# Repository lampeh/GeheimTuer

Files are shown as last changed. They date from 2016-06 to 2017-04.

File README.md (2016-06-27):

# GeheimTuer
Simple sliding door control at Attraktor Makerspace

User Interface:
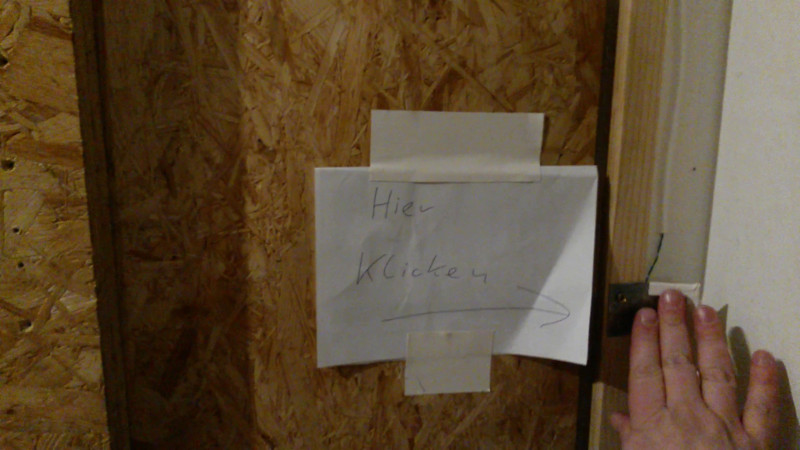
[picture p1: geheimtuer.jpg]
GeheimTuer (http://static.openchaos.org/attraktor/bastel/geheimtuer.mp4)


Prototype 1:
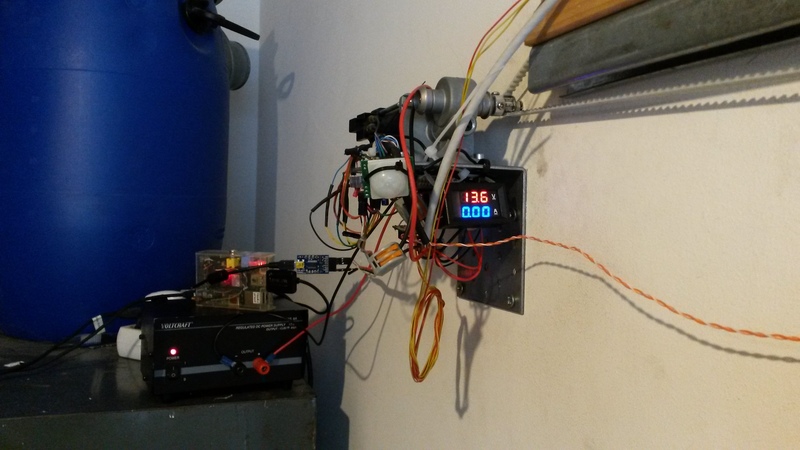
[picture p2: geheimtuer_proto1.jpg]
Prototype 1


Prototype 2:
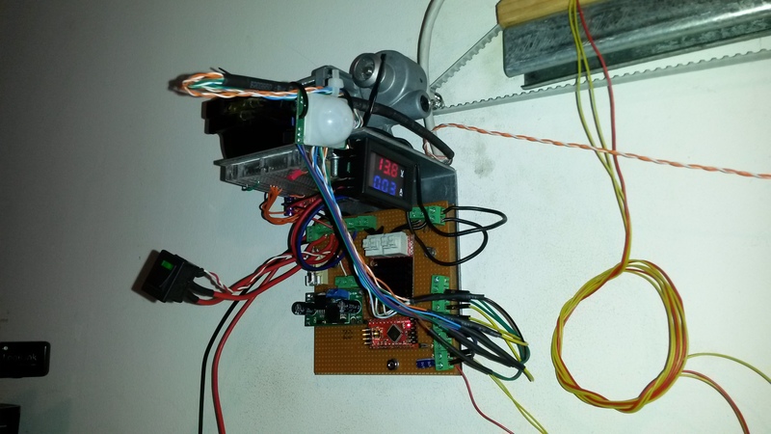
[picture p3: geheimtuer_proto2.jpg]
Prototype 2


Prototype 3, now with laser case and cooling fan:
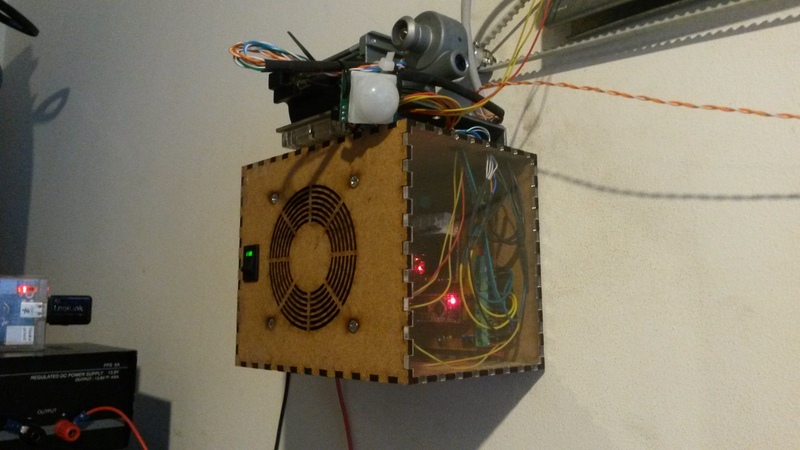
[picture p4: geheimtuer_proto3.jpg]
Prototype 3


Spaghetti Schematics. Just a reminder to myself:
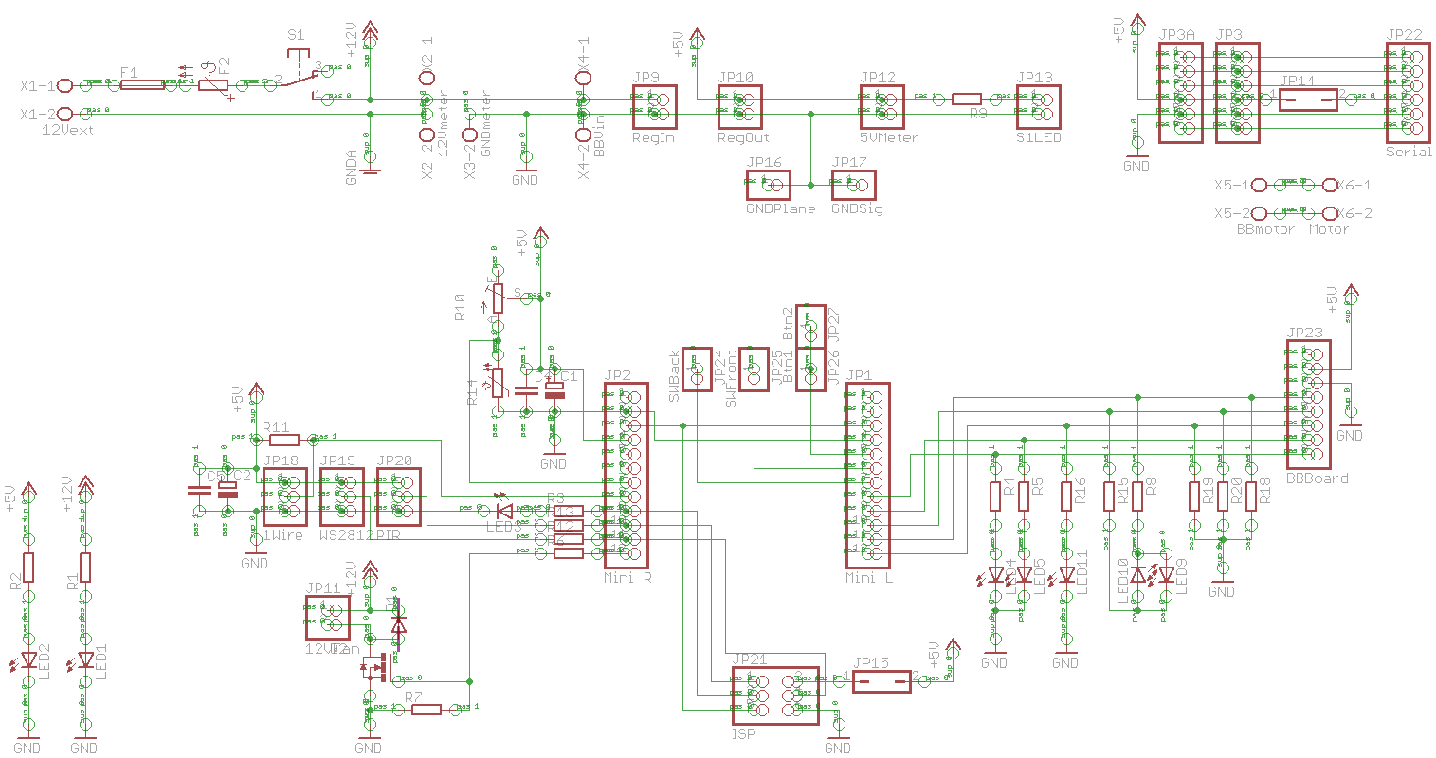
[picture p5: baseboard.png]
Baseboard


Case (created with [Tabbed Box Maker](https://github.com/paulh-rnd/TabbedBoxMaker)):
Case Cut

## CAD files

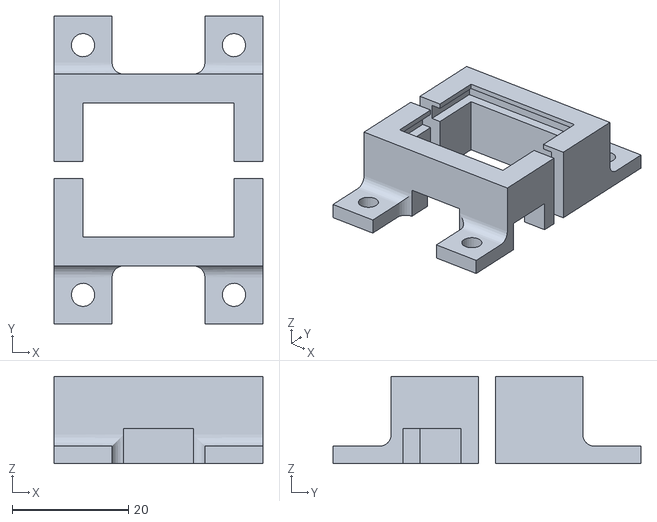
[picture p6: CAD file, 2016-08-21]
ledcover_bracket.stl
36.0 x 53.0 x 15.0

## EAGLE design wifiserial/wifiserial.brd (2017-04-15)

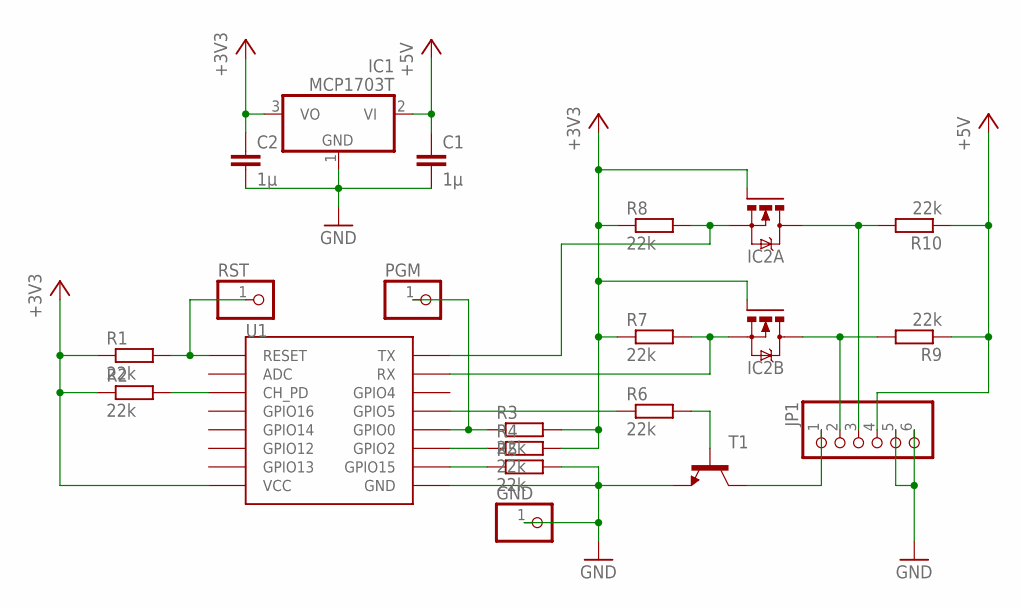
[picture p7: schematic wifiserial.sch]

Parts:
C1, C2: 1µ; C0805K
GND: PINHD-1X1; 1X01
IC1: MCP1703T; SOT-89
IC2: NFET2-SSOT6; SSOT-6
JP1: PINHD-1X6; 1X06
PGM: PINHD-1X1; 1X01
R1, R2, R3, R4, R5, R6, R7, R8, R9, R10: 22k; R0805
RST: PINHD-1X1; 1X01
T1: -NPN-SOT23-EBC; SOT23-EBC
U1: ESP12SMD; ESP12-SMD

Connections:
+3V3: C2.1, IC1.3 (VO), IC2.1 (G), IC2.3 (G), R1.1, R2.1, R3.2, R4.2, R7.1, R8.1, U1.VCC
+5V: C1.1, IC1.2 (VI), JP1.4, R9.1, R10.1
GND: C1.2, C2.2, GND.1, IC1.1 (GND), JP1.5, JP1.6, R5.2, T1.E, U1.GND
unnamed: PGM.1, R3.1, U1.GPIO0
unnamed: R4.1, U1.GPIO2
unnamed: R5.1, U1.GPIO15
unnamed: R2.2, U1.CH_PD
unnamed: R1.2, RST.1, U1.RESET
unnamed: R6.1, U1.GPIO5
unnamed: R6.2, T1.B
unnamed: IC2.4 (D), JP1.2, R9.2
unnamed: IC2.6 (D), JP1.3, R10.2
unnamed: JP1.1, T1.C
unnamed: IC2.5 (S), R8.2, U1.TXD0 (TX)
unnamed: IC2.2 (S), R7.2, U1.RXD0 (RX)

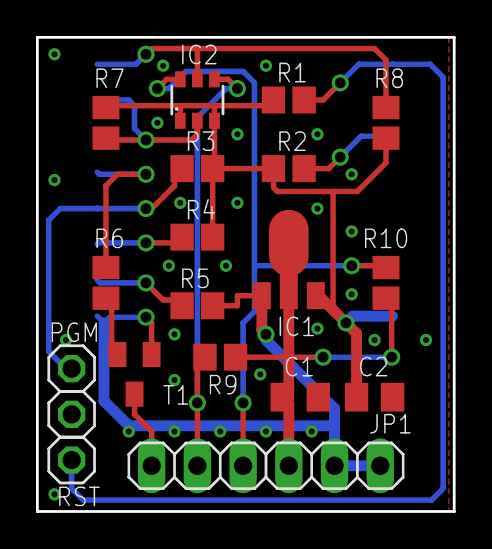
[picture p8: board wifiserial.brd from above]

Board: 2 copper layers, 23.2 x 26.3 mm, 20 parts (1 on the bottom side), 15 nets.

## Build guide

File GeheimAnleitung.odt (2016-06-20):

### Bedienungsanleitung:

1. Knopf drücken. Tür öffnet.
2. Türschwelle überschreiten. Wohlfühlen.
3. Tür schließt automatisch.

### Tür offenhalten:

1. Knopf drücken. Tür öffnet.
2. Bei offener Tür Knopf erneut drücken. Tür bleibt offen.
3. Zum Schließen der Tür Knopf ein weiteres Mal drücken.

### Bei Problemen während der Fahrt:

1. Knopf drücken. Tür stoppt.
2. Nach dem Problem Knopf erneut drücken. Tür öffnet.
3. Tür schließt automatisch.

Grün | Blinkt | Vorsicht! Tür schliesst gleich.
Grün | Faded | Tür zu. Alles gut.
Gelb | Blinkt | Bewegungsmelder meldet Bewegung. Tür bleibt solange offen.
Rot | Leuchtet | Tür blockiert durch Knopfdruck. Knopf erneut drücken.
Rot | Blinkt | Endschalter nicht erreicht. Knopf drücken zum Öffnen.
Rot | Faded | Nicht gut. Motortreiberstörung. Tür funktioniert nicht.
Blau | Leuchtet | Komisch. Techniker informieren. Tür funktioniert nicht.

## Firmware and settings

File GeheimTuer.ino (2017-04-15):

#include <avr/pgmspace.h>
#include <WS2812.h>
#include <OneWire.h>
#include "Debounce.h"
#include "Motor.h"


/* config */

#define VERSION "v1.1 " __TIMESTAMP__
#define MAXPIX 20  // LED stripe length
#define EXTRAPIX 4 // animation buffer, read window moves back and forth EXTRAPIX pixels

#if ((EXTRAPIX) > 255)
#error EXTRAPIX must fit uint8_t ledidx variable
#endif

// WS2812 data
const int ledPin = 11;

// I/O connections to bridge driver module
// https://www.olimex.com/Products/RobotParts/MotorDrivers/BB-VNH3SP30/
// https://www.olimex.com/Products/RobotParts/MotorDrivers/BB-VNH3SP30/resources/BB-VNH3SP30_schematic.pdf
const int motorDiagAPin = 5;
const int motorDiagBPin = 6;
const int motorInAPin = 7;
const int motorInBPin = 8;
const int motorPWMPin = 9;

Motor motor(motorDiagAPin, motorDiagBPin, motorInAPin, motorInBPin, motorPWMPin);

// end-stop switches, active-low
// Panasonic AZ7121
const int switchFront = 3; // front is at the closed position
const int switchBack = 4;

// wire-ORed buttons, active-low
const int switchTrigger = 2;

// PIR sensor, active-high
// based on BIS0001, e.g.: https://learn.adafruit.com/pir-passive-infrared-proximity-motion-sensor/
const int pirPin = 12;

// on-board status LED
const int statusLED = 13;

// on-board 1-wire sensors
OneWire ds(A0);

// external 1-wire bus
OneWire iButton(A1);

// PWM fan control
const int fanPWMPin = 10;


/* motor driver */

// slow seek to end-stop, used if door is in unknown position
const struct Motor::accelProfile accelProfileLow[] PROGMEM = {
  {
    maxMillis: 13000,
    stepMillis: 5,
    add: 1,
    factor: 1,
    minPWM: 0,
    maxPWM: 64,
  },
  {
    maxMillis: 0
  }
};

// normal operation
// try accelerating as fast as possible without skipping belt teeth
// belt tension limits torque. important safety feature
// TODO: install less stiff spring between belt and door to dampen the initial pull
const struct Motor::accelProfile accelProfileHigh[] PROGMEM = {
  { // accelerate and keep running
    maxMillis: 2500,
    stepMillis: 4,
    add: 1,
    factor: 1,
    minPWM: 0,
    maxPWM: 255,
  },
  { // slow down before end-stop
    maxMillis: 1500,
    stepMillis: 75,
    add: 0,
    factor: 0.9,
    minPWM: 50,
    maxPWM: 255,
  },
  { // seek end-stop
    maxMillis: 2500,
    stepMillis: 100,
    add: -1,
    factor: 1,
    minPWM: 50,
    maxPWM: 64,
  },
  {
    maxMillis: 0
  }
};

struct Motor::accelProfile currentProfile; // RAM-cached profile block
const struct Motor::accelProfile *accelProfile; // pointer to current profile block in progmem


/* WS2812 LEDs */

cRGB leds[MAXPIX + EXTRAPIX];
cRGB tmp_leds[MAXPIX]; // temp array for fading and blinking
cRGB *ledptr; // read pointer for WS2812 library, points to start of window

// requires custom changes to accept uint8_t** argument
WS2812 LED(MAXPIX, &ledptr);

enum ledMode { ledSolid, ledFade, ledBlink, ledForward, ledBackward } ledMode;

// mode-dependent state
union ledState {
  uint8_t ledidx;
  signed int fader;
  bool blink_off;
} ledState;

// pre-defined colors. GRB order, g++ doesn't implement out-of-order initializers
const cRGB traktor = {g: 0xB8 / 7, r: 0x67 / 7, b: 0xDC / 7}; // https://wiki.attraktor.org/Corporate_Identity
const cRGB black = {g: 0x00, r: 0x00, b: 0x00};
const cRGB white = {g: 0x1F, r: 0x1F, b: 0x1F};
const cRGB red = {g: 0x00, r: 0x1F, b: 0x00};
const cRGB yellow = {g: 0x1F, r: 0x1F, b: 0x00};
const cRGB green = {g: 0x1F, r: 0x00, b: 0x00};
const cRGB blue = {g: 0x00, r: 0x00, b: 0x1F};


/* unsorted variables below. TODO: refactor & cleanup */

// buttons & switches do different things in different states
enum doorStates { doorClosed, doorOpening, doorOpen, doorClosing, doorBlocked, doorBlockedPir, doorError } doorState;

double drivePWM;

// TODO: the timing system has some quirks. think again or document

unsigned long lastMillis = 0; // last loop's millis() result

unsigned long driveMillis;
unsigned long driveProfileMillis;
unsigned long driveTotalMillis;

const unsigned long openInterval = 3000; // ms before the door closes again, unless blocked by button
unsigned long openMillis = 0;

const unsigned long debounceInterval = 2; // shift inputs into debounce register every debounceInterval ms
unsigned long debounceMillis = 0;

const unsigned int debounceIgnoreInterval = 150; // ignore buttons for debounceIgnoreInterval*debounceInterval ms
unsigned int debounceIgnore = 0;

// TODO: use structured profiles
unsigned long ledMillis = 0;
const unsigned long ledSolidInterval = 500; // constantly update LED stripe in solid mode
const unsigned long ledFadeInterval = 40;
const unsigned long ledBlinkInterval = 500;
unsigned long ledMoveInterval; // shift LED window every X ms - varied by drivePWM

const unsigned long ledMoveMin = 45; // minimum move interval if drivePWM == 255
const unsigned long ledMoveMax = 300; // maximum move interval if drivePWM == 0

const unsigned int dsMax = 3; // register at most dsMax DS18B20 sensors
byte dsAddrs[dsMax][8]; // 1-wire addresses
byte dsCount; // registered sensors
signed int dsResults[dsMax];

unsigned long dsMillis = 0;
const unsigned long dsInterval = 1000; // sensor read interval
const signed int tempMax = 38 / 0.0625; // run fan at full speed above tempMax
const signed int tempMin = 30 / 0.0625; // run fan at minimum speed at tempMin
const signed int tempHyst = 2 / 0.0625; // shut off fan at tempMin-tempHyst

union sensorData {
  uint8_t scratchpad[9];
  struct {
    int16_t temperature;
    union {
      uint16_t userdata;
      struct {
        int8_t th;
        int8_t tl;
      };
    };
    union {
      uint8_t config;
      struct {
        uint8_t : 5;
        uint8_t resolution : 2;
        uint8_t : 1;
      };
    };
    uint8_t reserved0, reserved1, reserved2;
    uint8_t crc;
  };
};

byte fanPWM;
const byte fanMin = 170; // minimum PWM limit
const byte fanMax = 255; // maximum PWM limit
bool fanOverride = false; // temperature control disabled if true

PinDebounce motorDiagA(motorDiagAPin);
PinDebounce motorDiagB(motorDiagBPin);

PinDebounce swFront(switchFront);
PinDebounce swBack(switchBack);
PinDebounce swTrigger(switchTrigger);
PinDebounce pirTrigger(pirPin);

unsigned long iButtonMillis = 0;
const unsigned long iButtonInterval = 40; // ms between scans for iButton devices on external 1-wire bus
Debounce iButtonTrigger(4); // 4bit debounce -> 3 successive iButton reads to trigger


void debug(const __FlashStringHelper *const string) {
  Serial.print(lastMillis);
  Serial.write(' ');
  Serial.print(string);
}


__attribute__((always_inline))
void setup() {
  Serial.begin(115200);
  debug(F("\r\nGeheimTuer " VERSION "\r\nDoor control init\r\n"));

  // disable driver bridges until setup complete
  motor.disable();

  pinMode(statusLED, OUTPUT);
  digitalWrite(statusLED, HIGH);

  // start fan on full speed
  pinMode(fanPWMPin, OUTPUT);
  digitalWrite(fanPWMPin, HIGH);
  fanPWM = 255;

  // initialize WS2812 LEDs
  setLeds1(traktor, ledSolid);
  ledptr = &leds[0];
  LED.setOutput(ledPin);
  LED.sync();

  // TODO: check driver power dissipation
  // base PWM frequency is ~31kHz. any divisor other than 1 makes the motor whine
  // VNH3SP30 datasheet limits the input PWM frequency to 10kHz. MOSFETs in thermal danger?
  setPwmFrequency(motorPWMPin, 1); // also affects fan PWM output

  digitalWrite(motorPWMPin, LOW);
  pinMode(motorPWMPin, OUTPUT);

  digitalWrite(motorInAPin, LOW);
  pinMode(motorInAPin, OUTPUT);

  digitalWrite(motorInBPin, LOW);
  pinMode(motorInBPin, OUTPUT);

  pinMode(switchFront, INPUT_PULLUP);
  pinMode(switchBack, INPUT_PULLUP);

  pinMode(switchTrigger, INPUT_PULLUP);

  pinMode(pirPin, INPUT);

  // register sensors
  dsCount = scan1Wire(dsAddrs, dsMax);

  // initialize debounce registers, assume steady state
  swFront.init();
  swBack.init();
  swTrigger.init();
  pirTrigger.init();

  iButtonTrigger.init(searchButton());

  debug(F("Door status: "));

  if (swTrigger() == LOW || iButtonTrigger() == HIGH || (swFront() == LOW && swBack() == LOW)) {
    doorState = doorError;
    setLeds1(blue, ledSolid);
    Serial.print(F("ERROR\r\n"));
  } else if (swFront() == LOW) {
    doorState = doorClosed;
    setLeds1(green, ledFade);
    Serial.print(F("closed\r\n"));
  } else {
    doorState = doorBlocked;
    setLeds1(red, ledSolid);
    Serial.print(F("blocked\r\n"));
  }

  if (doorState != doorError) {
    if (doorState != doorBlocked) {
      motor.brake();
    } else {
      motor.free();
    }

    // enable driver
    motor.enable();

    // diag pull-ups should have brought the lines up by now
    motorDiagA.init();
    motorDiagB.init();
  }

  digitalWrite(statusLED, LOW);
}


__attribute__((always_inline))
void loop() {
  unsigned long elapsedMillis;
  unsigned long currentMillis;

  currentMillis = millis();


  // fast debounce driver error signals to filter short glitches
  motorDiagA.update();
  motorDiagB.update();

  // The WAM is overheating!
  if ((motorDiagA() == LOW || motorDiagB() == LOW) && doorState != doorError) {
    motor.free();
    debug(F("Motor driver error condition - door disabled\r\n"));
    setLeds1(red, ledFade);
    doorState = doorError;
  }


  if (currentMillis == lastMillis) {
    // everything below runs on a ms scale
    return;
  }

  // let the processor handle the overflow
  elapsedMillis = currentMillis - lastMillis;
  lastMillis = currentMillis;
  // assume that none of the following intervals overflow


  debounceMillis += elapsedMillis;
  if (debounceMillis >= debounceInterval) {
    debounceMillis = 0;

    if (!debounceIgnore) {
      swTrigger.update();
    } else {
      debounceIgnore--;
    }

    pirTrigger.update();
    swFront.update();
    swBack.update();
  }


  iButtonMillis += elapsedMillis;
  if (iButtonMillis >= iButtonInterval) {
    iButtonMillis = 0;

    iButtonTrigger.update(searchButton());

    if (iButtonTrigger() == HIGH) {
      swTrigger(LOW);
      iButtonTrigger(LOW);
    }
  }


/*
  // remote debugging aid
  // TODO: formalize the commands
  if (Serial.available()) {
    switch (Serial.read()) {
      case 'x':
        swTrigger(LOW); break;
      case 'X':
        swTrigger(HIGH); break;
      case 'b':
        swBack(LOW); break;
      case 'B':
        swBack(HIGH); break;
      case 'f':
        swFront(LOW); break;
      case 'F':
        swFront(HIGH); break;
      case 'i':
        pirTrigger(HIGH); break;
      case 'I':
        pirTrigger(LOW); break;
      case 'm':
        debug(F("Door status: "));
        Serial.println(doorState);
        break;
      case 'h':
        motor.disable();
        setLeds1(red, ledFade);
        doorState = doorError;
        break;
      case 'r':
        motor.enable();
        setLeds1(red, ledSolid);
        doorState = doorBlocked;
        break;
      case 'k': {
          const cRGB white255 = {g: 0xFF, r: 0xFF, b: 0xFF};
          setLeds1(white255, ledSolid);
          break;
        }
      case 'K':
        setLeds1(black, ledSolid);
        break;
      case '1':
        dsCount = scan1Wire(dsAddrs, dsMax);
        break;
      case 'l':
        debug(F("Fan full\r\n"));
        digitalWrite(fanPWMPin, HIGH);
        fanOverride = true;
        fanPWM = 255;
        break;
      case 'L':
        fanOverride = false;
        break;
    }
  }
*/


  // add up dsMillis early, so the door driver can reset it
  dsMillis += elapsedMillis;


  switch (doorState) {
    case doorClosed:
      // wait until a button is pressed or the front switch opens
      if (swTrigger() == LOW || swFront() == HIGH) {
        if (swTrigger() == LOW) {
          swTrigger(HIGH); // re-arm swTrigger
          debounceIgnore = debounceIgnoreInterval;
          debug(F("Button switch triggered - opening door\r\n"));
          initDrive(Motor::motorBackward, accelProfileHigh);
        } else {
          // maybe someone tried to pull the door open
          // TODO: or the door slams too fast into the end-stop and rebounds. align profile & inertial reality
          debug(F("Front switch triggered - opening door\r\n"));
          initDrive(Motor::motorBackward, accelProfileLow);
        }
        setLeds2(white, black, EXTRAPIX, ledBackward);
        doorState = doorOpening;
      }
      break;

    case doorOpen:
      // hold the door open if button pressed during openInterval
      if (swTrigger() == LOW) {
        motor.free();
        debug(F("Button switch triggered - door blocked\r\n"));
        swTrigger(HIGH);
        setLeds1(red, ledSolid);
        doorState = doorBlocked;
        break;
      }

      // reset timeout while sensor input is HIGH
      if (pirTrigger() == HIGH) {
        debug(F("Motion sensor triggered - door blocked by PIR\r\n"));
        setLeds1(yellow, ledBlink);
        doorState = doorBlockedPir;
        break;
      }

      openMillis += elapsedMillis;
      if (openMillis >= openInterval || swBack() == HIGH) {
        if (swBack() == HIGH) {
          // maybe someone tried to pull the door closed
          // TODO: or the door slams too fast into the end-stop and rebounds. align profile & inertial reality
          debug(F("Back switch triggered - closing door\r\n"));
          initDrive(Motor::motorForward, accelProfileLow);
        } else {
          debug(F("openInterval timeout - closing door\r\n"));
          initDrive(Motor::motorForward, accelProfileHigh);
        }
        setLeds2(white, black, EXTRAPIX, ledForward);
        doorState = doorClosing;
      }
      break;

    case doorOpening:
      // are we there yet?
      if (swBack() == LOW) {
        motor.brake();
        debug(F("Back switch triggered - door open\r\n"));
        debug(F("Total ms: "));
        Serial.println(driveTotalMillis);
        openMillis = 0;
        setLeds1(green, ledBlink);
        doorState = doorOpen;
        break;
      }

    // fall-through to doorClosing

    case doorClosing:
      if (doorState == doorClosing && swFront() == LOW) {
        motor.brake();
        debug(F("Front switch triggered - door closed\r\n"));
        debug(F("Total ms: "));
        Serial.println(driveTotalMillis);
        setLeds1(green, ledFade);
        doorState = doorClosed;
        break;
      }

      // stop if button pressed while in motion
      if (swTrigger() == LOW) {
        motor.free(); // TODO: motor.brake() might be better for an emergency stop. doesn't make much different in our case, the belt skips and the door stops in both cases
        debug(F("Button switch triggered - door blocked\r\n"));
        swTrigger(HIGH);
        setLeds1(red, ledSolid);
        doorState = doorBlocked;
        break;
      }

      // keep fan on full while driving
      digitalWrite(fanPWMPin, HIGH);
      fanPWM = 255;

      // don't poll 1-wire temperature sensors while driving
      dsMillis = 0;

      driveTotalMillis += elapsedMillis;
      driveMillis += elapsedMillis;

      if (driveMillis >= currentProfile.stepMillis) {
        driveProfileMillis += driveMillis;
        driveMillis = 0;

        // switch to next profile step
        if (driveProfileMillis >= currentProfile.maxMillis) {
          driveProfileMillis = 0;

          // load profile block from progmem
          _memcpy_P(&currentProfile, ++accelProfile, sizeof(currentProfile));

          // end-stop not reached at end of profile, someone might be in the way
          if (currentProfile.maxMillis == 0) {
            motor.free();
            debug(F("End of profile - door blocked\r\n"));
            debug(F("Total ms: "));
            Serial.println(driveTotalMillis);
            setLeds1(red, ledBlink);
            doorState = doorBlocked;
            break;
          }

          debug(F("Next profile\r\n"));
        }

        // update PWM value
        double newDrivePWM = (drivePWM + currentProfile.add) * currentProfile.factor;

        if (newDrivePWM < currentProfile.minPWM) {
          newDrivePWM = currentProfile.minPWM;
        } else if (newDrivePWM > currentProfile.maxPWM) {
          newDrivePWM = currentProfile.maxPWM;
        }

        drivePWM = newDrivePWM;
        analogWrite(motorPWMPin, round(newDrivePWM));

        // update LED animation speed
        ledMoveInterval = ledMoveMin + (unsigned long)((255 - newDrivePWM) * ((double)(ledMoveMax - ledMoveMin) / 255));

        debug(F("Drive PWM: "));
        Serial.print(newDrivePWM);
        Serial.print(F(", ledMoveInterval: "));
        Serial.println(ledMoveInterval);
      }
      break;

    case doorBlockedPir:
      // motion stopped, return to work
      if (pirTrigger() == LOW) {
        if (swBack() == LOW) {
          debug(F("Motion sensor released - door open\r\n"));
          openMillis = 0;
          setLeds1(green, ledBlink);
          doorState = doorOpen;
        } else {
          debug(F("Motion sensor released - door blocked\r\n"));
          setLeds1(red, ledSolid);
          doorState = doorBlocked;
        }
      }

      // hold the door open if button pressed
      if (swTrigger() == LOW) {
        motor.free();
        debug(F("Button switch triggered - door blocked\r\n"));
        swTrigger(HIGH);
        setLeds1(red, ledSolid);
        doorState = doorBlocked;
      }
      break;

    case doorBlocked:
      // wait until a button is pressed
      if (swTrigger() == LOW) {
        swTrigger(HIGH);

        // close door only if end-stop is active
        if (swBack() == LOW) {
          debug(F("Button switch triggered - closing door\r\n"));
          ledMode = ledForward;
          doorState = doorClosing;
          initDrive(Motor::motorForward, accelProfileHigh);
        } else {
          debug(F("Button switch triggered - opening door\r\n"));
          ledMode = ledBackward;
          doorState = doorOpening;
          initDrive(Motor::motorBackward, accelProfileLow);
        }

        setLeds2(white, black, EXTRAPIX, ledMode);
      }
      break;

    case doorError:
      // wait until driver cools down
      if (motorDiagA() == HIGH && motorDiagB() == HIGH) {
        debug(F("Motor driver recovered - door blocked\r\n"));
        fanOverride = false;
        setLeds1(red, ledSolid);
        doorState = doorBlocked;
        //        digitalWrite(statusLED, LOW);
      } else {
        fanPWM = 255;
        fanOverride = true;
        digitalWrite(fanPWMPin, HIGH);
        digitalWrite(statusLED, HIGH);
      }
      break;

    default:
      motor.free();
      motor.disable();
      debug(F("BUG: invalid doorState value: "));
      Serial.print(doorState);
      Serial.print(F(" - door disabled\r\n"));
      setLeds1(blue, ledSolid);
      doorState = doorError;
      digitalWrite(statusLED, HIGH);
      break;
  }


  ledMillis += elapsedMillis;
  switch (ledMode) {
    case ledSolid:
      if (ledMillis >= ledSolidInterval) {
        ledMillis = 0;
        ledptr = &leds[0];
        LED.sync();
      }
      break;

    case ledFade: {
        if (ledMillis >= ledFadeInterval) {
          ledMillis = 0;

          // TODO: really scale the values. this is too cheap
          for (size_t i = 0; i < MAXPIX; i++) {
            tmp_leds[i].r = max(0, (int)leds[i].r - abs(ledState.fader));
            tmp_leds[i].g = max(0, (int)leds[i].g - abs(ledState.fader));
            tmp_leds[i].b = max(0, (int)leds[i].b - abs(ledState.fader));
          }

          if (ledState.fader++ >= 255) {
            ledState.fader = -254;
          }

          ledptr = &tmp_leds[0];

          // quick hack: blink outer LEDs if someone approaches the door
          // TODO: fix double period at fader counter limits
          if (pirTrigger() == HIGH) {
            if ((ledState.fader >> 4) % 2) {
              tmp_leds[0] = {g: 0xFF, r: 0xFF, b: 0x00};
              tmp_leds[MAXPIX - 1] = {g: 0xFF, r: 0xFF, b: 0x00};
            } else {
              tmp_leds[1] = {g: 0xFF, r: 0xFF, b: 0x00};
              tmp_leds[MAXPIX - 2] = {g: 0xFF, r: 0xFF, b: 0x00};
            }
          }

          LED.sync();
        }
        break;
      }

    case ledBlink:
      if (ledMillis >= ledBlinkInterval) {
        ledMillis = 0;

        if (!ledState.blink_off) {
          ledptr = &leds[0];
        } else {
          // setLeds zeroed tmp_leds
          ledptr = &tmp_leds[0];
        }

        ledState.blink_off = !ledState.blink_off;

        LED.sync();
      }
      break;

    case ledBackward:
      if (ledMillis >= ledMoveInterval) {
        ledMillis = 0;

        if (ledState.ledidx >= EXTRAPIX) {
          ledState.ledidx = 0;
        }

        // move window forward
        ledptr = &leds[ledState.ledidx++];
        LED.sync();
      }
      break;

    case ledForward:
      if (ledMillis >= ledMoveInterval) {
        ledMillis = 0;

        if (ledState.ledidx == 0) {
          ledState.ledidx = EXTRAPIX;
        }

        // move window backwards
        ledptr = &leds[--ledState.ledidx];
        LED.sync();
      }
      break;

    default:
      debug(F("BUG: invalid ledMode value: "));
      Serial.println(ledMode);
      setLeds1(blue, ledSolid);
      digitalWrite(statusLED, HIGH);
      break;
  }

  if (dsMillis >= dsInterval) {
    dsMillis = 0;

    union sensorData sensorData;
    signed int maxTemp;
    byte dsRead = 0;

    for (byte i = 0; i < dsCount; i++) {
      if (!ds.reset()) {
        // no presence pulse detected
        continue;
      }

      // read temperature
      ds.select(dsAddrs[i]);
      ds.write(0xBE);

      for (byte j = 0; j < sizeof(sensorData.scratchpad); j++) {
        sensorData.scratchpad[j] = ds.read();
      }

      if (OneWire::crc8(sensorData.scratchpad, 8) == sensorData.crc) {
        signed int temp = sensorData.temperature;

        // filter small fluctuations in sensor output
        if (abs(temp - dsResults[i]) < 2) {
          temp = dsResults[i];
        } else {
          dsResults[i] = temp;
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

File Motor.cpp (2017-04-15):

#include <avr/pgmspace.h>
#include <Arduino.h>
#include "Motor.h"

/*
static void _memcpy_P(void *dest, const void *src, size_t n) {
  for (size_t i = (n >> 2); i > 0; i--) {
    *(uint32_t *)dest = pgm_read_dword(src);
    dest += 4;
    src += 4;
  }

  n -= (n >> 2) * 4;

  while (n--) {
    *(uint8_t *)(dest++) = pgm_read_byte(src++);
  }
}



// set profile pointer, reset counters, set driver inputs
void initDrive(const enum motorDir dir, const struct accelProfile *const profile) {
  accelProfile = profile;

  _memcpy_P(&currentProfile, accelProfile, sizeof(currentProfile));

  if (currentProfile.maxMillis == 0) {
    motorFree();
    motorDisable();

    //debug(F("BUG: invalid accelProfile: maxMillis == 0 - door disabled"));

    doorState = doorError;
    setLeds1(blue, ledSolid);
    digitalWrite(statusLED, HIGH);

    return;
  }

  drivePWM = 0;

  driveTotalMillis = driveProfileMillis = 0;
  driveMillis = currentProfile.stepMillis; // TODO: this is a hackish way to start driving without waiting the first stepMillis interval

  //  motorDir = dir;
  setMotorDir(dir);
}
*/

void Motor::setMotorBits(const bool A, const bool B) {
  digitalWrite(motorPWMPin, LOW);
  digitalWrite(motorInAPin, A);
  digitalWrite(motorInBPin, B);
}

void Motor::_free() {
  setMotorBits(LOW, LOW);
}

void Motor::_brake() {
  _free();
  digitalWrite(motorPWMPin, HIGH);
}

void Motor::_forward() {
  setMotorBits(HIGH, LOW);
}

void Motor::_backward() {
  setMotorBits(LOW, HIGH);
}

void Motor::free() {
  _free();
  //debug(F("Brake released\r\n"));
}

void Motor::brake() {
  _brake();
  //debug(F("Brake engaged\r\n"));
}

void Motor::forward() {
  _forward();
  //debug(F("Forward\r\n"));
}

void Motor::backward() {
  _backward();
  //debug(F("Backward\r\n"));
}

void Motor::disable() {
  // actively pull diag pins low, disables both driver bridges
  digitalWrite(motorDiagAPin, LOW);
  pinMode(motorDiagAPin, OUTPUT);

  digitalWrite(motorDiagBPin, LOW);
  pinMode(motorDiagBPin, OUTPUT);

  //debug(F("Motor driver disabled\r\n"));
}

void Motor::enable() {
  // return control to pull-ups on the driver board
  pinMode(motorDiagAPin, INPUT);
  pinMode(motorDiagBPin, INPUT);

  //debug(F("Motor driver enabled\r\n"));
}

void Motor::setMotorDir(const enum motorDir dir) {
  switch (dir) {
    case motorForward:
      forward();
      break;

    case motorBackward:
      backward();
      break;

    default:
      break;
  }
}

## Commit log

2016-06-12 Typical Arduino Krumpelcode. Passes all tests, though.
2016-06-14 - quick linear accel works better than slow exponential increase - remote-control debugging - output currentMillis over Serial - changed line endings to \r\n
2016-06-14 added serial debug command to disable driver
2016-06-14 check driver condition before switches
2016-06-14 another small profile adjustment - brake earlier for smooth ending
2016-06-17 cosmetics: use debug(), free motor before Serial.print, typo
2016-06-17 UI experiment: vary ledMoveInterval with drivePWM
2016-06-17 removed sample video from git repo
2016-06-17 branch on short enum motorDir instead of int dir
    [GeheimTuer.ino]
2016-06-18 experiment: PIR sensor to keep the door open needs more testing
2016-06-19 - start ledBlink in the on-state - PIR debug
2016-06-19 - display correct mode colors on startup
    [GeheimTuer.ino]
2016-06-19 - initialize WS2812 before Serial - set LEDs to blue on setup error
    [GeheimTuer.ino]
2016-06-20 Logic Analyzer confirms: PWM freq is ~31kHz
2016-06-21 pre-adjustment. belt connector needs work
2016-06-27 laser-cut case & cooling fan
2016-06-27 Spaghetti Schematics. Just a reminder to myself.
2016-06-27 laser-cut case
2016-06-29 experimental: DS18B20 temperature sensors on-board - inefficent code - DS18B20 are too slow - really need a PTC or NTC as planned
    [GeheimTuer.ino]
2016-07-02 print sensor debug output only on change
2016-07-05 update package: - set watchdog timeout - another profile adjustment, removed slow-start - uint8_t -> byte - fanOverride for remote control - increased minimum sensor difference to 2 - TODO: use class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
2016-07-06 fan motor diode
2016-08-21 3D-printed brackets for LED cover - 3mm notch for translucent acrylic cover - G-Code for Attraktor 3D printer included
    [ledcover_bracket.stl]
2016-08-21 missing fillet in STL export
    [ledcover_bracket.stl]
2016-10-02 - Disable WDT. doesn't work well with Arduino bootloader. Think again
    [GeheimTuer.ino]
2016-10-02 - changed temperature limits
2016-10-02 - quick hack: blink outer LEDs if someone approaches the door
2016-10-02 - fan full/min debug output
2016-10-02 - focus group test: ignore double-clicks on the buttons when opening
2016-10-02 - reshuffled the motor bits. no change in function
2017-04-14 ESP-12 board connected to Arduino serial
    [wifiserial.brd, wifiserial.sch]
2017-04-14 visible layers
    [wifiserial.brd]
2017-04-15 moved to subdirs
    [wifiserial.brd, wifiserial.sch]
2017-04-23 Arduino IDE really wants the directory to be named GeheimTuer
